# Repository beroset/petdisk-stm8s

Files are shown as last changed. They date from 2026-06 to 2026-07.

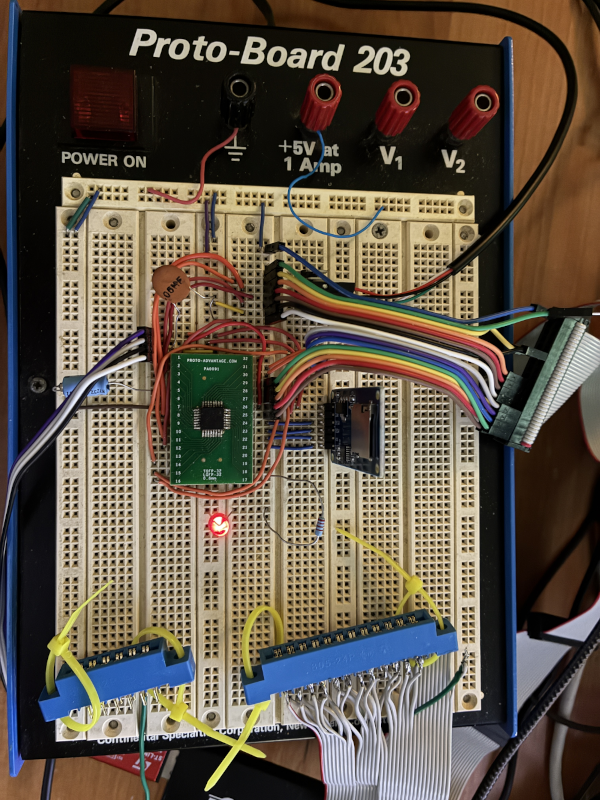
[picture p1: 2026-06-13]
doc/images/circuit.png

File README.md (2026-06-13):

# petdisk-stm8s
Interfacing the Commodore PET to a microSD card via the IEEE-488 bus using the STM8S microcontroller.

## Prerequisites
You must have `CMake`, the [`sdcc`](https://sdcc.sourceforge.net/) compiler (version 4.4 or newer) and [`stm8flash`](https://github.com/vdudouyt/stm8flash) to flash the result into the target hardware.

## Building the firmware
The code uses [CMake](https://cmake.org/) to create the build system.  On the Fedora Linux machine I use, here's the toolchain file:

```
set(CMAKE_SYSTEM_NAME Generic)
set(CMAKE_C_COMPILER /usr/bin/sdcc-sdcc)
set(CMAKE_TRY_COMPILE_TARGET_TYPE STATIC_LIBRARY)
```

Note that for this system, the `sdcc-sdcc` file is a shell script:
```
#!/usr/bin/sh
PATH=/usr/libexec/sdcc:/usr/libexec/sdcc/x86_64-redhat-linux-gnu/12.1.0:$PATH
/usr/libexec/sdcc/sdcc "$@"
```

If you use another distro, you may need to explicitly set the path something like this.

Here's the command line to set it up:
```
cmake -B build -S . -DCMAKE_TOOLCHAIN_FILE=~/toolchain-sdcc.cmake
```

Then to build and flash in one step:
```
cmake --build build -t flash
```

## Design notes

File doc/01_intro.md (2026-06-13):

# Introduction {#mainpage} #

A Commodore PET to microSD card interface.

## Problem overview

I bought my first computer, a Commodore PET in 1977 and I still have it and [recently restored](https://github.com/beroset/pet_resto) it.  The PET used audio cassette tapes for program and data storage, and while that works, more or less, there's not a convenient way to use a modern computer to write cassette tapes in the PET's format.

So, the idea for this project is to connect the PET to a microSD card.  This would allow me to use high capacity modern storage media.  Indeed, a 64G microSD card would probably be able to store all the software ever written for the PET, so this seems adequate.

### Previous work
Doing some searching for the PET, I encountered two other closely related projects:

https://github.com/bitfixer/petdisk

https://github.com/bitfixer/petdisk-max

These both seem quite usable.  The first uses an Arduino, and the second one uses an ESP32.  One nice feature implemented is the ability to use a connection to a computer via WiFi as a simulated disk.

There are also commercially available devices, including from [Tynemouth Software](https://www.tindie.com/stores/tynemouth/) in the U.K. who make all manner of interesting things for old computers.

This project, however, is primarily intended to:

 - provide an opportunity to learn about the STM8 processor
 - provide an opportunity to learn about microSD card interfacing
 - build something fun
 - describe the process by which such things are described so that others might be inspired

## Process
The general process by which one creates a microprocessor based embedded system can be summarized in these steps:

 1. Identify interfaces
 2. Choose microprocessor
 3. Assign interfaces to microprocessor pins
 4. Identify other needed electronics & design the circuit
 5. Build the circuit
 6. Write the software
 7. Test

The rest of this document uses these steps as the outline.

## Identify interfaces

There are two major interfaces.  They are the IEEE-488 interface from the PET, and the microSD card.  In addition, it is often helpful to have a UART (serial port) available for debugging and an LED for status indications.

## Choose microprocessor
Previous work, as mentioned above, used an AVR microprocessor, and an ESP32.  This project will use an STMicroelectronics STM8S105K6T6C processors. It's a 16MHz 8-bit processor that with Harvard architecture and 3-stage pipeline in a 32-pin LQFP package. It feature 32K of FLASH, 2K of RAM, 1K of EEPROM, SPI, I2C, UART and several timers.  It can also operate at voltages from 2.95V to 5.5V.  Very usefully for this project, it has an internal RC oscillator, so very few external parts are needed, and the cost per CPU is less than $1.

## Assign interfaces to microprocessor pins
In the diagram below, the IEEE-488 port connections to the PET are shown on a diagram of the STM8S pinout.  Color codes are shown in the table.

Interface | color
----------|---------
IEEE-488  | cyan
microSD   | dark blue
ground    | orange
+5V       | light red
serial    | light green
LED       | yellow

@image html pin_assignments.png "Pin assignments"
@image latex pin_assignments.png "Pin assignments"

Here are the pin assignments in table format:

Pin | Function                                | Description      |
----|-----------------------------------------|------------------|
 1  | NRST                                    | 100nF to GND     |
 2  | OSCIN/PA1                               | IEEE-488 DAV     |
 3  | OSCOUT/PA2                              | IEEE-488 NRFD    |
 4  | VSS                                     | GND              |
 5  | VCAP                                    | 2.2uF to GND     |
 6  | VDD                                     | +5V              |
 7  | VDDIO                                   | +5V              |
 8  | AIN12/PF4                               | IEEE-488 NDAC    |
 9  | VDDA                                    | +5V              |
 10 | VSSA                                    | GND              |
 11 | [I2C_SDA] AIN5/PB5                      | IEEE-488 ATN     |
 12 | [I2C_SCL] AIN4/PB4                      | IEEE-488 EOI     |
 13 | [TIM1_ETR] AIN3/PB3                     | no connection    |
 14 | [TIM1_CH3N] AIN2/PB2                    | IEEE-488 DIO6    |
 15 | [TIM1_CH2N] AIN1/PB1                    | IEEE-488 DIO7    |
 16 | [TIM1_CH1N] AIN0/PB0                    | IEEE-488 DIO8    |
 17 | PE5/SPI_NSS                             | 2.2K ohm + LED   |
 18 | PC1 (HS)/TIM1_CH1/UART2_CK              | no-connection    |
 19 | PC2 (HS)/TIM1_CH2                       | no-connection    |
 20 | PC3 (HS)/TIM1_CH3                       | no-connection    |
 21 | PC4 (HS)/TIM1_CH4                       | SD card CS       |
 22 | PC5 (HS)/SPI_SCK                        | SD card CLK      |
 23 | PC6 (HS)/SPI_MOSI                       | SD card MOSI     |
 24 | PC7 (HS)/SPI_MISO                       | SD card MISO     |
 25 | PD0 (HS)/TIM3_CH2 [TIM1_BKIN] [CLK_CCO] | IEEE-488 DIO1    |
 26 | PD1 (HS)/SWIM                           | IEEE-488 DIO2    |
 27 | PD2 (HS)/TIM3_CH1 [TIM2_CH3]            | IEEE-488 DIO3    |
 28 | PD3 (HS)/TIM2_CH2 [ADC_ETR]             | IEEE-488 DIO4    |
 29 | PD4 (HS)/TIM2_CH1 [BEEP]                | IEEE-488 DIO5    |
 30 | PD5/UART2_TX                            | serial TX        |
 31 | PD6/UART2_RX                            | serial RX        |
 32 | PD7/TLI [TIM1_CH4]                      | no-connection    |

## Identify other needed electronics & design the circuit
For this project, since the IEEE-488 bus runs with 5V logic, but a microSD card runs on 3.3V logic, level translation is required.  For this purpose a modern, high-speed level converter such as the SN74LVC245APW is a good choice.  It will also require a 3.3V power supply, which can be very simply constructed using a LM1117-3.3 to provide 3.3V from 5V input.

In addition, we will need a 500nF decoupling capacitor near the power rails of the CPU, a 100nF capacitor for the NRST line to ground, and a 2.2uF capacitor connecting VCAP on pin 5 to ground.

Finally, the circuit needs a LED and current limiting resistor. The particular red LED chosen here has a forward voltage drop of 2.0V and an open drain output of this processor can easily safely sink 10mA, so we use Ohm's law to calculate an appropriate resistor.  \f(V/I = R\f) so calculate \f((5V - 2.0V)/10mA = 300\f) ohms, and the closest standard resistor value is 270 ohms, which gives a resulting current of 11mA.

TODO: add a proper schematic

## Build the circuit
For getting the circuit up and running quickly, a breadboard is useful.  An adapter board was used to allow the use of the LQFP package to the breadboard.  Additionally, a microSD module incorporating both the 3.3V power supply and level converters provides a convenient package for the circuitry that is needed to connect a microSD card to a 5V CPU.

@image html circuit.png "Completed circuit on breadboard"
@image latex circuit.png "Completed circuit on breadboard"

## Write the software
The details of the software are described in most of this manual; this section describes the process of creating the software.

Generically, the first consideration is tools, including compilers, linkers, debuggers and whatever else might be needed to create embedded software.  For this project and this CPU, the chosen tools are [SDCC](https://sdcc.sourceforge.net/) which is the Small Device C Compiler.  It's an open source compiler suite that has support for the STM8 processor used in this project.

To program the part while it is in-circuit, one can use the open source [stm8flash](https://github.com/vdudouyt/stm8flash) tool with an ST-Link programming device, which is an inexpensive piece of hardware (inexpensive clones are available under $10) that connects a computer to the circuit for programming and debugging.

Creating software for embedded systems is different from creating software for a typical desktop computer.  The first obvious difference is that developing software for a desktop machine usually means also developing that software on the same full-featured machine which already has an operating system, keyboard, mouse, and display.

Embedded systems often start with none of those, so cross-development is typically used.  That is, one develops the embedded software *on* a regular computer, but *for* the embedded system.

### First program
The first thing the is often done is to get some simple thing working first.  For many embedded systems, blinking an LED is that first task.  This has several benefits, including that:

 - it's simple
 - it provides a test that the toolchain works and is configured correctly
 - it gives immediate visual feedback that the CPU is working
 - it requires minimal external circuitry

### Next software steps, generically
Often the next useful thing to do is to enable the UART so that we can connect that to the development computer and conveniently print debugging messages or allow for simple serial requests.

## Test
It's most often useful to start with small subsystems, such as blinking LED and serial port, and then move on to more complex ones.

# Further reading
A more detailed overview of this project's architecture is describe in [architecture](@ref architecture)

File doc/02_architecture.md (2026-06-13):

# Software Architecture {#architecture}

This page describes the software architecture of the project.

## Overview
As mentioned in the [introduction](@ref mainpage) page, there are two main hardware interfaces: the IEEE-488 bus and the microSD card.

### IEEE-488 bus

Here's an overview of how it works, but interested readers are strongly encouraged to check the [references](@ref references) for details of how the IEEE-488 bus works and how the Commodore PET uses it.

There is an 8-bit bidirectional data portion of the interface which is how data and addresses are transferred.  There are five interface control lines and three transfer control lines.  This table shows the names of the IEEE-488 bus lines and what it means:

Name    | Function        |  Group            |
--------|-----------------|-------------------|
DIO1    | data in/out     | data bus          |
DIO2    | data in/out     | data bus          |
DIO3    | data in/out     | data bus          |
DIO4    | data in/out     | data bus          |
DIO5    | data in/out     | data bus          |
DIO6    | data in/out     | data bus          |
DIO7    | data in/out     | data bus          |
DIO8    | data in/out     | data bus          |
REN     | Remote Enable   | interface mgmt    |
IFC     | Interface Clear | interface mgmt    |
SRQ     | Service Request | interface mgmt    |
ATN     | Attention       | interface mgmt    |
EOI     | End or Identify | interface mgmt    |
DAV     | Data Valid      | transfer control  |
NRFD    | Not Ready For Data | transfer control  |
NDAC    | Not Data Accepted  | transfer control  |

The PET is hardwired to act as the sole controller on the IEEE-488 bus, which means that anything connecting to the PET can only act as a peripheral device.  With the IEEE-488 bus, such devices can operate as a Talker, a Listener or both.  

In brief, the PET asserts ATN and sends an address on the data bus.  Then ATN is de-asserted, and data is transferred with a handshake using DAV, NRFD and NDAC.  The first diagram shows just a primary and secondary address being transmitted.  Note that signals are active low.

@startuml
binary "ATteNtion" as ATN
binary "DAta Valid" as DAV
binary "Not Ready For Data" as NRFD
binary "Not Data ACcepted" as NDAC
concise "Data" as D
@0
ATN is High
DAV is High
NRFD is High
NDAC is Low
D is {-}
@1 
ATN is Low
@2
D is pri_addr
@3
DAV is Low
@4
NRFD is Low
@5
NDAC is High
@6
DAV is High
@7
NDAC is Low
D is {-}
@8 
NRFD is High
@9
D is sec_addr
@10
DAV is Low
@11
NRFD is Low
NDAC is High
@12
DAV is High
@13
NRFD is High
NDAC is Low
D is {-}
@14
ATN is High
@enduml

The second timing diagram shows the transfer of data immediately after the addressing shown above.  This sequence happens repeatedly until the last date byte, when the EOI line is also asserted (pulled low).

@startuml
binary "ATteNtion" as ATN
binary "DAta Valid" as DAV
binary "Not Ready For Data" as NRFD
binary "Not Data ACcepted" as NDAC
concise "Data" as D
@0
ATN is High
DAV is High
NRFD is High
NDAC is Low
D is {-}
@1 
D is data
@2
DAV is Low
@3
NRFD is Low
NDAC is High
@4
DAV is High
@5
NDAC is Low
D is {-}
NRFD is High
@enduml

### microSD card
The microSD interface can operate in a serial mode via a standard 3-wire SPI bus interface, which is the most common way it is used in embedded systems.  The only additional line needed is a CS (Chip Select) which would allow a host microprocessor to talk with multiple devices, but only select one at a time. 

## Further resources {#references}
### IEEE-488
One valuable resource describing the details of how the IEEE-488 bus works and is implemented on the Commodore PET is a book published in 1980.  I bought my softcover copy at Computerland in 1981, but it's now also available on [the Internet Archive](https://archive.org/details/PET_and_the_IEEE488_Bus).  The book is _PET and the IEEE 488 Bus (GPIB)_ , published in 1980 by OSBORNE/McGraw Hill, and written by Fisher, E. R. (Eugene Ralph), 1940-; Jensen, C. W. (C. William).

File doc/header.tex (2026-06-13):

% Latex header for doxygen 1.16.1
  % Handle batch mode
  $latex_batchmode

  % to overcome problems with too many open files
  \let\mypdfximage\pdfximage\def\pdfximage{\immediate\mypdfximage}

  \RequirePackage{iftex}
  \ifLuaTeX
    \directlua{pdf.setminorversion(7)}
  \fi
  \ifXeTeX
    \special{pdf:minorversion 7}
  \fi
  \ifPDFTeX
    \pdfminorversion=7
  \fi

  % Set document class depending on configuration
%%BEGIN COMPACT_LATEX
  \documentclass[twoside]{article}
%%END COMPACT_LATEX
%%BEGIN !COMPACT_LATEX
  \documentclass[twoside]{book}
%%END !COMPACT_LATEX
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
   % 2) file with the name of the emoji without the .png extension
   % in case image exist use this otherwise use the ':<text>:' form
   \newcommand{\doxygenemoji}[2]{%
     \IfFileExists{$latexemojidirectory/#2.png}{\raisebox{-0.1em}{}}{#1}%
   }

  % Page & text layout
  \usepackage{geometry}
  \geometry{%
    $papertype,%
    top=2.5cm,%
    bottom=2.5cm,%
    left=2.5cm,%
    right=2.5cm%
  }
  \usepackage{changepage}

  % Allow a bit of overflow to go unnoticed by other means
  \tolerance=750
  \hfuzz=15pt
  \hbadness=750
  \setlength{\emergencystretch}{15pt}
  \setlength{\parindent}{0cm}
  \newcommand{\doxynormalparskip}{\setlength{\parskip}{3ex plus 2ex minus 2ex}}
  \newcommand{\doxytocparskip}{\setlength{\parskip}{1ex plus 0ex minus 0ex}}
  \doxynormalparskip
  % Redefine paragraph/subparagraph environments, using sectsty fonts
  \makeatletter
  \renewcommand{\paragraph}{%
    \@startsection{paragraph}{4}{0ex}{-1.0ex}{1.0ex}{%
      \normalfont\normalsize\bfseries\SS@parafont%
    }%
  }
  \renewcommand{\subparagraph}{%
    \@startsection{subparagraph}{5}{0ex}{-1.0ex}{1.0ex}{%
      \normalfont\normalsize\bfseries\SS@subparafont%
    }%
  }
  \makeatother

  \makeatletter
  \newcommand\hrulefilll{\leavevmode\leaders\hrule\hskip 0pt plus 1filll\kern\z@}
  \makeatother

  % Headers & footers
  \usepackage{fancyhdr}
  \pagestyle{fancyplain}
  \renewcommand{\footrulewidth}{0.4pt}

  \fancypagestyle{fancyplain}{
    \fancyhf{}
    \fancyhead[LE, RO]{\bfseries\thepage}
    \fancyhead[LO]{\bfseries\rightmark}
    \fancyhead[RE]{\bfseries\leftmark}
    \fancyfoot[LO, RE]{\bfseries\scriptsize $generatedby Doxygen }
  }

  \fancypagestyle{plain}{
    \fancyhf{}
    \fancyfoot[LO, RE]{\bfseries\scriptsize $generatedby Doxygen }
    \renewcommand{\headrulewidth}{0pt}
  }

  \pagestyle{fancyplain}

%%BEGIN !COMPACT_LATEX
  \renewcommand{\chaptermark}[1]{%
    \markboth{#1}{}%
  }
%%END !COMPACT_LATEX
  \renewcommand{\sectionmark}[1]{%
    \markright{\thesection\ #1}%
  }

  % ToC, LoF, LoT, bibliography, and index
  % Indices & bibliography
  \usepackage[numbers]{natbib}
  \usepackage[titles]{tocloft}
  \setcounter{tocdepth}{3}
  \setcounter{secnumdepth}{5}

  % creating indexes
  $makeindex

  $extralatexpackages

  $latexspecialformulachars

%%BEGIN FORMULA_MACROFILE
  \input{$formulamacrofile}
%%END FORMULA_MACROFILE

  % Hyperlinks
%%BEGIN PDF_HYPERLINKS
    % Hyperlinks (required, but should be loaded last)
    \ifPDFTeX
      \usepackage[pdftex,pagebackref=true]{hyperref}
    \else
      \ifXeTeX
        \usepackage[xetex,pagebackref=true]{hyperref}
      \else
        \ifLuaTeX
          \usepackage[luatex,pagebackref=true]{hyperref}
        \else
          \usepackage[ps2pdf,pagebackref=true]{hyperref}
        \fi
      \fi
    \fi
    \hypersetup{%
      colorlinks=true,%
      linkcolor=blue,%
      citecolor=blue,%
      unicode,%
      pdftitle={$projectname},%
      pdfsubject={$projectbrief}%
    }

%%END PDF_HYPERLINKS

  % Custom commands used by the header
  % Custom commands
  \newcommand{\clearemptydoublepage}{%
    \newpage{\pagestyle{empty}\cleardoublepage}%
  }

  % caption style definition
  \usepackage{caption}
  \captionsetup{labelsep=space,justification=centering,font={bf},singlelinecheck=off,skip=4pt,position=top}

  % in page table of contents
  \IfFormatAtLeastTF{2023/05/01}{\usepackage[deeplevels]{etoc}}{\usepackage[deeplevels]{etoc_doxygen}}
  \etocsettocstyle{\doxytocparskip}{\doxynormalparskip}
  \etocsetlevel{subsubsubsection}{4}
  \etocsetlevel{subsubsubsubsection}{5}
  \etocsetlevel{subsubsubsubsubsection}{6}
  \etocsetlevel{subsubsubsubsubsubsection}{7}
  \etocsetlevel{paragraph}{8}
  \etocsetlevel{subparagraph}{9}

  % prevent numbers overlap the titles in toc
  \renewcommand{\numberline}[1]{#1~}

% End of preamble, now comes the document contents
%===== C O N T E N T S =====

\begin{document}
  \raggedbottom

  $latexdocumentpre

  % Titlepage & ToC
%%BEGIN PDF_HYPERLINKS
%%BEGIN USE_PDFLATEX
    % To avoid duplicate page anchors due to reuse of same numbers for
    % the index (be it as roman numbers)
    \hypersetup{pageanchor=false,
                bookmarksnumbered=true,
                pdfencoding=unicode
               }
%%END USE_PDFLATEX
%%END PDF_HYPERLINKS
  \pagenumbering{alph}
  \begin{titlepage}
  \vspace*{7cm}
  \begin{center}%
  {\Large $title}\\
%%BEGIN PROJECT_NUMBER
  [1ex]\large $projectnumber \\
%%END PROJECT_NUMBER
  \vspace*{1cm}
  {\large $projectbrief}\\
  
%%BEGIN TIMESTAMP
    \vspace*{0.5cm}
    {\small $datetime}
%%END TIMESTAMP
  \end{center}
  \end{titlepage}

%%BEGIN !COMPACT_LATEX
  \clearemptydoublepage
%%END !COMPACT_LATEX
  \pagenumbering{roman}

  \tableofcontents
%%BEGIN !COMPACT_LATEX
  \clearemptydoublepage
%%END !COMPACT_LATEX
  \pagenumbering{arabic}

%%BEGIN PDF_HYPERLINKS
%%BEGIN USE_PDFLATEX
  % re-enable anchors again
  \hypersetup{pageanchor=true}
%%END USE_PDFLATEX
%%END PDF_HYPERLINKS

%--- Begin generated contents ---

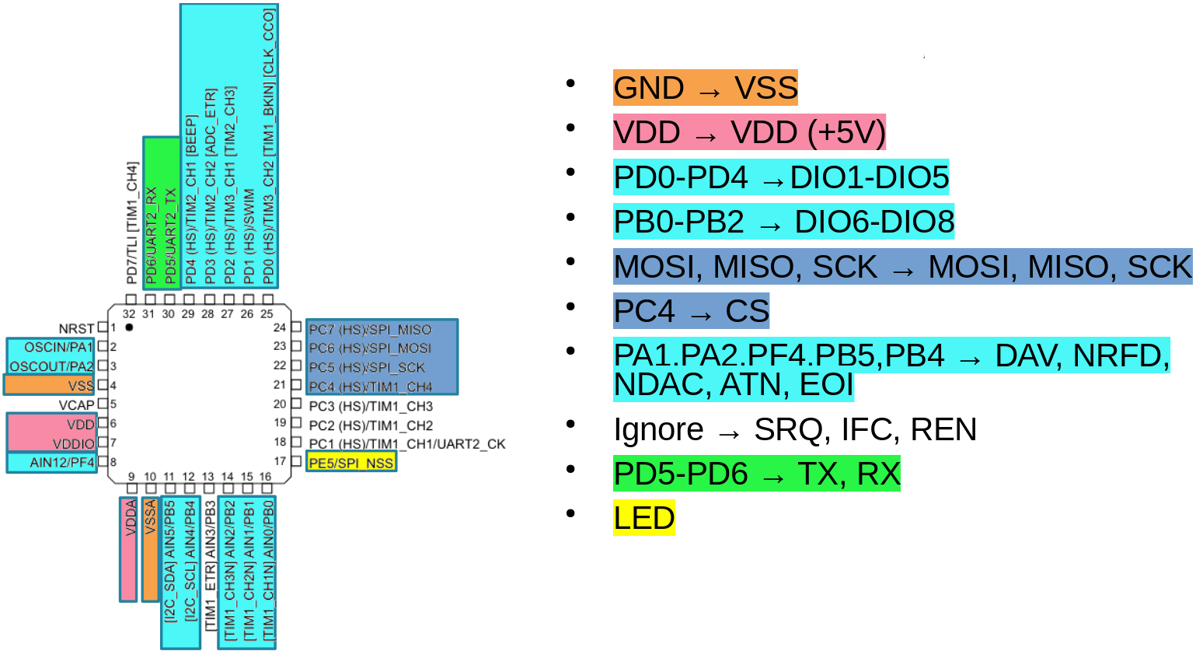
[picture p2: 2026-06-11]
doc/images/pin_assignments.png

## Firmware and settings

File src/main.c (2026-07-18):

#include <stdint.h>
#include <stdio.h>
#include "stm8.h"
#include "timer.h"
#include "uart.h"
#include "pindefs.h"
#include "ff.h"
#include "diskio.h"

#if 0
unsigned char __sdcc_external_startup(void) {
    return 0;
}
#endif

void timer2_isr(void) __interrupt(TIM2_OVF_ISR)
{
    // clear IT pending bit
    BITCLR(TIM2_SR1, 0);
    // toggle LED
    FLIP(LED);
}

static void init()
{
    const uint16_t tim2_reload_value = 15625;

    CLK_CKDIVR = 0x18; // Set the frequency to 2 MHz; T=0.5us
    TIM2_PSCR = 0b00000111;  // prescaler = 7; T=64us
    TIM2_ARRH = tim2_reload_value >> 8;
    TIM2_ARRL = tim2_reload_value & 0x00ff;
    TIM2_IER = 0x01;  // update interrupt enable
    TIM2_CR1 = 0x01;  // enable timer

    timer_init();

    // set up LED output
    OUT(LED);
    SCR1(LED);
    CCR2(LED);

    uart_init();
}


static void reset_on_halt()
{
    WWDG_CR = 0x80;
}

void die (		/* Stop with dying message */
	FRESULT rc	/* FatFs return value */
)
{
	printf("Failed with rc=%u.\n", rc);
}
void fatprint(FATFS *fat)
{
    printf("fs_type %d\n", fat->fs_type);
    printf("csize %d\n", fat->csize);
    printf("fatbase %ld\n", fat->fatbase);
    printf("dirbase %ld\n", fat->dirbase);
}

static void dumpmem(const BYTE* buff, UINT sz) {
    for (UINT n = 0; n < sz; ++n, ++buff) {
        if ((n & 0xf) == 0) {
            printf("\n%04x:", n);
        }
        printf(" %02x", *buff & 0xff);
    }
    putchar('\n');
}

static void dumpdir(const DIR* dir) {
    printf("size of dir = %d\n", sizeof(DIR));
    printf("dptr = 0x%lx, clust = 0x%lx, sect = 0x%lx\n\"", dir->dptr, dir->clust, dir->sect);
    for (int i=0; i < 11; ++i) {
        if (i == 8) putchar('.');
        putchar(dir->fn[i]);
    }
    dumpmem(dir->dir, 16);
    printf("\" flag = %02x\n", dir->fn[11]);
}

FRESULT list_dir (const char *path)
{
    FRESULT res;
    DIR dir;
    FILINFO fno;
    int nfile, ndir;


    res = f_opendir(&dir, path);                   /* Open the directory */
    if (res == FR_OK) {
        nfile = ndir = 0;
        for (;;) {
            res = f_readdir(&dir, &fno);           /* Read a directory item */
            if (fno.fname[0] == 0) break;          /* Error or end of dir */
            if (fno.fattrib & AM_DIR) {            /* It is a directory */
                printf("   <DIR>   %s\n", fno.fname);
                ndir++;
            } else {                               /* It is a file */
                printf("%10lu %s\n", fno.fsize, fno.fname);
                nfile++;
            }
        }
        f_closedir(&dir);
        printf("%d dirs, %d files.\n", ndir, nfile);
    } else {
        printf("Failed to open \"%s\". (%u)\n", path, res);
    }
    return res;
}

void test() {
    FRESULT rc;
    // disk things
    FATFS fatfs;			/* File system object */
    FIL file;			/* File object */
    UINT bw, br, i;
    uint8_t buff[64];
    static const char write_text[] = "Hello world!\r\n";

    printf("\nMount a volume.\n");
    rc = f_mount(&fatfs, "", 0);
    if (rc) die(rc);

    if (!rc) {
        printf("\nOpen a test file (message.txt).\n");
        rc = f_open(&file, "MESSAGE.TXT", FA_OPEN_ALWAYS | FA_READ);
        // try again if it doesn't work the first time
        if (rc == FR_NOT_READY) {
            rc = f_open(&file, "MESSAGE.TXT", FA_OPEN_ALWAYS | FA_READ);
        }
        if (rc) die(rc);
    }
    fatprint(&fatfs);
    if (!rc) {
        printf("\nType the file contents.\n");
        for (;;) {
            rc = f_read(&file, &buff, sizeof(buff), &br);	/* Read a chunk of file */
            if (rc || !br) break;			/* Error or end of file */
            for (i = 0; i < br; i++)		/* Type the data */
                putchar(buff[i]);
        }
        if (rc) die(rc);
    }
    rc = f_close(&file);
    if (rc) die(rc);

    if (!rc) {
        printf("\nOpen a file to write (write.txt).\n");
        rc = f_open(&file, "WRITE.TXT", FA_WRITE | FA_READ | FA_CREATE_ALWAYS);
        if (rc) die(rc);
    }
    if (!rc) {
        printf("\nWrite a text data. (Hello world!)\n");
        rc = f_write(&file, write_text, sizeof(write_text) - 1, &bw);
        if (!rc && bw != sizeof(write_text) - 1) rc = FR_DISK_ERR;
        if (rc) die(rc);
    }
    if (!rc) {
        printf("\nClose written file.\n");
        rc = f_close(&file);
        if (rc) die(rc);
    }

    if (!rc) {
        printf("\nRead root directory.\n");
        rc = list_dir("");
        if (rc) die(rc);
    }
    if (rc) {
        printf("\nTest FAILED.\n");
    } else {
        printf("\nTest completed.\n");
    }
    f_mount(0, "", 1);
}

void main(void)
{
    init();
    enableInterrupts();
    puts(" Hello\nPETski!");
    test();

    for (;;) {
        int command = getchar();
        switch (command) {
            case 'r':
                puts("Resetting now...\n");
                delay_ms(1000);
                reset_on_halt();
                break;
            default:
                // do nothing
        }
        waitForInterrupt();
    }
}

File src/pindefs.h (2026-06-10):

#ifndef PINDEFS_H
#define PINDEFS_H

#define MASTER_FREQ 2000000

/* pin definitions

    Display | STM8
    --------|-------
    RS      | PD0
    RW      | PC1
    EN      | PD2
    D4      | PB0
    D5      | PB1
    D6      | PB2
    D7      | PB3

*/

#define RS_PORT C
#define RS_BIT 1
#define RW_PORT C
#define RW_BIT 2
#define EN_PORT C
#define EN_BIT 3
#define DISPLAY_SPAN_PORT B
#define DISPLAY_SPAN_MASK 0x0f
#define DISPLAY_SPAN_SHIFT 0

/*
 * PB0 to PB3 are LCD DB4-DB7
 */

/*
 * SPI module
 *
 * Module  |  CPU  | color
 * --------|-------|------
 *   CS    |  PC4  | BLU
 *   SCL   |  PC5  | GRN
 *   MOSI  |  PC6  | YEL
 *   MISO  |  PC7  | ORG
 *   VCC   |  VDD  | RED
 *   GND   |  VSS  | BRN
 *
 * Note that the CS pin assignment can be changed, but the
 * three other SPI pins are fixed.
 */

#define CS_PORT C
#define CS_BIT 4
#define SCL_PORT C
#define SCL_BIT 5
#define MOSI_PORT C
#define MOSI_BIT 6
#define MISO_PORT C
#define MISO_BIT 7

#ifdef DEVBOARD
//#warning "LED is defined as PD7, not on-board LED"
/*
 * Note that because the on-board LED is on C5 which is also the SCL,
 * we can't use it.
 */
/*
 * LED
 */
#define LED_PORT D
#define LED_BIT 7
#else
//#warning "DEVBOARD is NOT defined"

/*
 * LED
 */
#define LED_PORT E
#define LED_BIT 5

/*
 * IEEE-488 bus
 */
/*
 *  IEEE-488 |  CPU  | color
 * ----------|-------|------
 *   DAV     |  PA1  | BRN
 *   NRFD    |  PA2  | RED
 *   NDAC    |  PF4  | ORG
 *   ATN     |  PB5  | YEL
 *   EOI     |  PB4  | WHT
 *
 * GND - BLK
 *   Unused: SRQ, IFC, REN
 */

#define DAV_PORT  A
#define DAV_BIT   1
#define NRFD_PORT A
#define NRFD_BI   2
#define NDAC_PORT F
#define NDAC_BIT  4
#define ATN_PORT  B
#define ATN_BIT   5
#define EOI_PORT  B
#define EOI_BIT   4

// PD0-PD7 => DIO1-DIO8
#define GPIB_SPAN_PORT D
#define GPIB_SPAN_MASK 0xff
#define GPIB_SPAN_SHIFT 0

#endif // DEVBOARD
#endif // PINDEFS_H

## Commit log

2026-04-18 Fix timer-based version
2026-04-25 Factor out include file, use WFI
    This factors out the register definitions into the stm8.h file and
    alters main to use the WFI instructions to shut everything down except
    for interrupts.
2026-04-25 Add 1ms timer and test code
    This adds a 1ms timer and a delay_ms() function that allows one to delay
    the given number of milliseconds using a hardware timer.
2026-04-26 Add delay_us() function to timer code
    This delay uses nops instead of a timer.
2026-05-09 Use macros for pin assignments
    This uses the port manipulation macros in main for clarity and
    maintainability.
2026-05-10 Add outline of SPI bus handling
2026-05-29 Combine pin definitions into a single header
2026-05-29 Change delay_us to calibrated macro
2026-05-29 Remove external clock pin from build
    This was only needed to calibrate the microsecond delay timer.
2026-05-29 Add color codes to GPIB wiring chart
2026-06-10 Devboard microsd (#2)
    * Add SDCard interface
    * Add SDCard to build
    * Update SPI routines for use in SDCard
    * Initialize SDCard in main
    * Change DEVBOARD not to use on-board LED
    * Remove bf-avr-sdlib
    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
2026-06-11 Add pin assignments picture
2026-06-25 Add fatfs library to replace pff
    The full fatfs library from Chen should work better than the
    stripped-down version that had been in use.
    [mkfs.xlsx]
2026-06-25 Attempt to get disk working with fatfs library
    This doesn't completely work yet, but it's a first step in the
    migration.
    [diskio.c]
2026-06-25 Complete pff→fatfs migration: remove pff, fix diskio.c (#4)
    * Remove pff directory and clean up diskio.c for fatfs migration
    * Fix CMD0: skip wait_ready before card enters SPI mode
    Before CMD0 puts the SD card into SPI mode, the card is in native
    SD mode and may not drive MISO high (0xFF) immediately after CS
    goes low. The wait_ready() call inside select() was timing out,
    causing send_cmd(CMD0) to return 0xFF instead of 0x01, which made
    disk_initialize always return STA_NOINIT.
    Fix: for CMD0 specifically, bypass select()/wait_ready() and use
    the same direct CS_L + one dummy read that the original working pff
    implementation used. All other commands continue to use the full
    select()/wait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
    [diskio.c]
2026-06-26 Fix SPI transfer overrun during SD writes
    [spi.c]
2026-06-26 Fix SPI master config and deselect hang risk
    [spi.c]
2026-06-26 Handle SPI busy timeout explicitly on deselect
2026-06-26 Use named SPI busy timeout constant
2026-06-26 Add SPI transfer timeouts and recovery
2026-06-26 Clarify SPI timeout loop semantics
2026-06-26 Document SPI timeout and recovery rationale
2026-06-26 Fix write test to close and report errors
    [main.c]
2026-06-26 Tighten write test sizing and SPI comments
    [main.c, spi.c]
2026-07-01 Add all tests and debugging
    This works with all tests, but there may be a timing issue still. When
    I omit the diskio debugging, it corrupts the disk.
    [diskio.c, main.c]
2026-07-07 Fix disk writes
    I don't know why this causes the code to work once again, but it does.
    I'll need to investigate further.
    [diskio.c]
2026-07-15 Work around compiler bug
    The code that was supposed to multiply by 512 did not seem to be
    correct, so it has been replaced with a function call which both yields
    correct results and results in a slightly smaller binary and the expense
    of a function call.
    [diskio.c]
